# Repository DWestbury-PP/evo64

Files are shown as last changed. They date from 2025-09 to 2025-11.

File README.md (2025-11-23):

# EVO64 Project

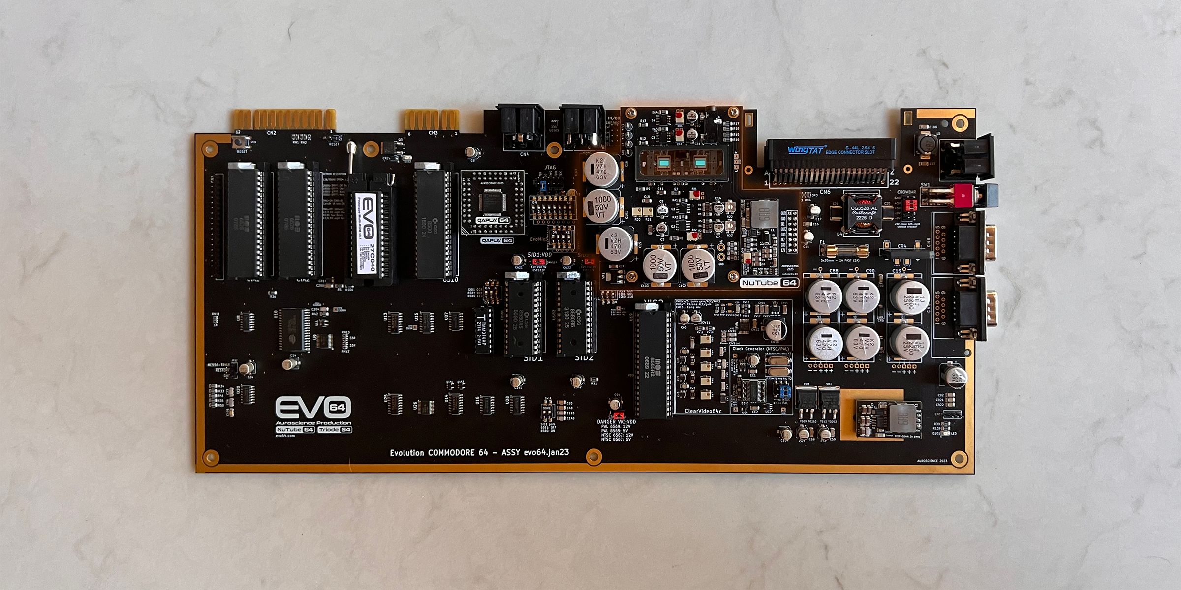
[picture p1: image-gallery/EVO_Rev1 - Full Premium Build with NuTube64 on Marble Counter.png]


## About EVO64

**EVO64** is a reimagining of the classic Commodore 64 with modern features and flourishes. This project brings the beloved C64 experience into the modern era while maintaining the authentic retro computing spirit that made the original so special.

### Key Features
EVO64 Logo

- **Modern Hardware Design** - Updated internals with contemporary components
- **Authentic Experience** - Maintains the classic C64 look, feel, and compatibility
- **Premium Build Quality** - High-quality components and construction
- **Extensive Documentation** - Comprehensive guides for builders and users
- **Community Support** - 3D printable accessories and mounting solutions

---

## Repository Contents

This repository contains supporting materials for the EVO64 project. While the hardware design and schematics remain proprietary, we're sharing essential resources for the community:

### Documentation (`/documentation/`)
Comprehensive guides and technical documentation:
- **EVO64 DIY Build Guide.pdf** - Complete assembly instructions
- **EVO64 Getting Started Guide.pdf** - Setup and initial configuration
- **EVO64 Product Brief.pdf** - Project overview and specifications
- **Technical Guides** - SID Audio, ROM Management, Tube Preamps, and more
- **Bill of Materials (BOM)** - Component lists for different configurations
- **MSM Command Sheet** - printable quick references by Retrosarge

### Image Gallery (`/image-gallery/`)
High-quality photos showcasing different EVO64 builds:
- Premium builds with NuTube64 and Triode64
- Various case configurations (Breadbin, Plexilaser, MODULR)
- Assembly photos and finished systems
- Prototype and development images

### Marketing Materials (`/promo-marketing/`)
- Project advertisements and promotional graphics

### 3D Printables (`/3D-printables/`)
Community-contributed 3D printing files organized by creator:
- **LCD Mounts** - 16x2 and 20x4 display mounting solutions
- **Keyboard Mounts** - Various case compatibility options
- **Cart Shield Covers** - Cartridge port protection
- **MSM Mounts** - Multi Switch Module mounting hardware
- **SIDKick & VIC-II Kawari** - Accessory housings
- **Case-Specific Mounts** - Plexi, C64c, and MODULR case accessories

### Interactive BOMs (`/ibom-html/`)
- Interactive HTML bill of materials for easy component identification

---

## Getting Started

### Prerequisites

This repository uses **Git Large File Storage (Git LFS)** to handle large files efficiently. You'll need:

1. **Git** (standard installation)
2. **Git LFS** - For handling large documentation PDFs, images, and 3D files

### Installation

#### Install Git LFS

**macOS (Homebrew):**
```bash
brew install git-lfs
```

**Windows:**
Download from [git-lfs.github.io](https://git-lfs.github.io/)

**Linux (Ubuntu/Debian):**
```bash
sudo apt install git-lfs
```

#### Clone the Repository

```bash
# Clone the repository
git clone https://github.com/[username]/evo64.git
cd evo64

# Initialize Git LFS (one-time setup)
git lfs install

# Pull all LFS files
git lfs pull
```

---

## Large Files Information

This repository contains **90 files** managed by Git LFS, totaling approximately **411 MB** of content including:

- **Documentation PDFs** (up to 123MB each)
- **High-resolution images** (up to 30MB each)
- **3D printing files** (STL and 3MF formats)
- **Excel spreadsheets** (BOMs and specifications)

### File Types Tracked by Git LFS:
- `*.pdf` - Documentation and guides
- `*.png`, `*.jpg`, `*.jpeg` - Images and photos
- `*.stl`, `*.3mf` - 3D printing files
- `*.xlsx` - Spreadsheets and BOMs

### For Contributors

When contributing new files:
- **Large files** (>25MB) will automatically be tracked by Git LFS
- **No special commands needed** - just add and commit normally
- The `.gitattributes` file handles LFS routing automatically

---

## Project Structure

```
evo64/
├── 3D-printables/             # Community 3D printing files
│   ├── Cart Shield Cover/     # Cartridge port covers
│   ├── Keyboard Mounts/       # Various keyboard mounting solutions
│   ├── LCD Mounts/            # Display mounting hardware
│   ├── MSM Mounts/            # Multi Switch Module mounts
│   └── [Various creators]/    # Organized by contributor
├── documentation/             # Technical documentation and guides
├── ibom-html/                 # Interactive bill of materials
├── image-gallery/             # Project photos and showcase images
├── Multi-SID Tester           # Player tool to test SID Addresses
├── promo-marketing/           # Marketing and promotional materials
└── README.md                  # This file
```

---

## Contributing

We welcome contributions to the supporting materials! Here's how you can help:

### 3D Printables
- Submit STL/3MF files for new mounting solutions
- Include photos of printed parts and installations
- Provide clear documentation for your designs

### Documentation Improvements
- Corrections and clarifications to existing guides
- Additional setup instructions for different configurations
- Translation contributions

### Images
- High-quality photos of your EVO64 build
- Different case configurations and setups
- Assembly process documentation

### Contribution Process
1. Fork the repository
2. Create a feature branch (`git checkout -b feature/new-mount-design`)
3. Add your files and documentation
4. Commit your changes (`git commit -m 'Add new LCD mount for XYZ case'`)
5. Push to the branch (`git push origin feature/new-mount-design`)
6. Open a Pull Request

---

## Important Notes

- **Hardware Design**: The PCB schematics and hardware design files are not included in this repository
- **Commercial Use**: Please respect any licensing terms associated with contributed files
- **File Sizes**: Large files are automatically handled by Git LFS - no special action required
- **Dependencies**: Some 3D printable designs may require specific hardware or case types

---

## Support & Community

- **Issues**: Report problems or request features via GitHub Issues
- **Discussions**: Join community discussions in GitHub Discussions
- **Documentation**: Check the `/documentation/` folder for detailed guides

---

## License

See the [LICENSE](LICENSE) file for details regarding the use of materials in this repository.

Individual contributors may have specific licensing terms for their submissions - please check individual file headers and accompanying documentation.

---

## Acknowledgments

Special thanks to all community contributors who have shared their 3D designs, documentation improvements, and build photos:

- **Sedor** - Multiple 3D printable designs and mounts
- **Jaystonian** - Keyboard mounting solutions
- **Perifractic** - C64c case compatibility mounts
- **BattleQuest** - MSM mounting hardware
- **Retrosarge** - MSM command sheet quick references
- And many others in the EVO64 community!

---
- All technical engineering work, including initial project conception, PCB design and extensive build testing by Dr. Stefano (aka Auroscience)
- Inspiration came from Hans Petter Dalsklev who worked on the C64 assembly 250407 board layout
- Inspiration for the ClearVideo64 video circuit came from Jay Desmarais (Jaystonian), however EVO’s implementations are unique and distinct
- Inspiration for Multi-SID and multi-ROM circuits came from Henning Liebenau, however EVO’s implementations are unique and distinct
- Inspiration for the “HeyBirt” Voltage Controlled Oscillator (VCO) / MOS 8701 Clock replacement circuit came from Jeff Birt (HeyBirt)
- The EVO64 logo, case badges and other branding have been developed by the Retro Badgeman
- Social media, tech documentation, web site maintenance & “innovative ideation” by Darrell Westbury
- Beta builds, testing and engineering support by Darrell Westbury, M. Bernardo (aka SX64Man) and H. Eckert.

---

*EVO64 - Bringing the C64 experience to the modern era*

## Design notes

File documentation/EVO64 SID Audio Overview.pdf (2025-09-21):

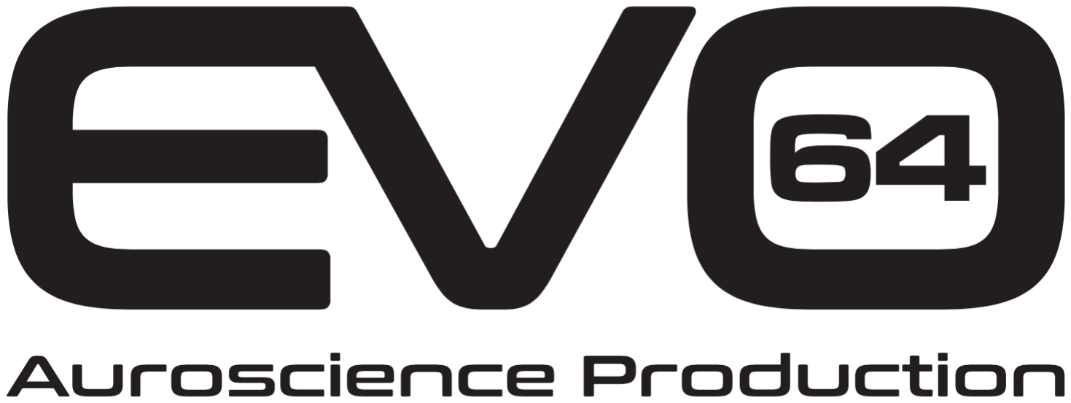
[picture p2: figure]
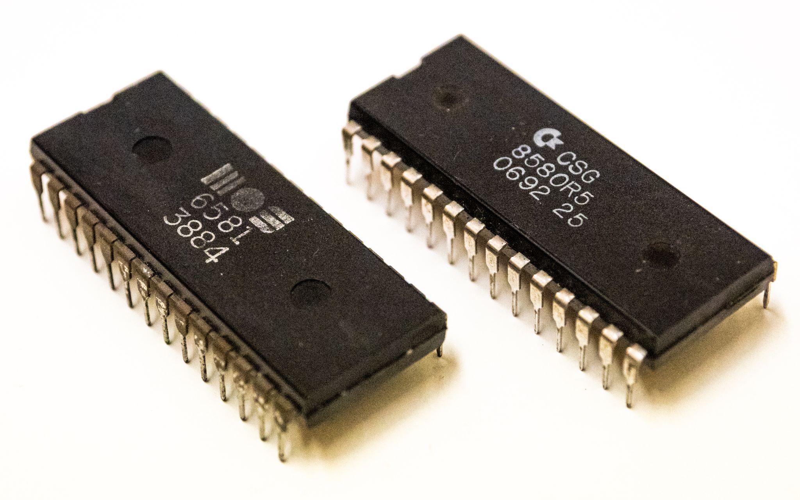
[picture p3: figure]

# “Double your Listening Pleasure”

One of the coolest features of the EVO is its native support for Dual SID chips and stereo sound output. The original inspirations came from the MixSID by Henning Liebenau, (http://henning-liebenau.de/mixsid/) although EVO takes a completely unique and novel approach by implementing all of its dual-SID addressing logic directly into a customized PLA we’re calling the QAPLA’. (https://docs.google.com/document/d/1FS7WOKs4T5evn5urdY_PP3zLMoXYe2qxybZdXSJ7aDo/edit?usp=sharing)

You may be familiar with some of the popular dual-SID solutions out there, which typically send the same (mono) audio signal to both SIDs at the same time. This can produce a nice “pseudo-Stereo effect”, when different types of SID chips are used (e.g., one 6581 and one 8580). This is due to the fact that your ears are hearing the different sound characteristics from the different chip models. EVO can reproduce this effect too of course, but it also goes much further…

EVO provides “True Stereo Sound”, by exposing the second SID to its own unique memory addresses. This enables different notes and effects to be played from each SID, providing software with access to 6x oscillator voices and 2x filters, for double the fun.

To ensure the best backwards compatibility, the primary SID on your EVO will always listen on address $D400, and by moving a simple jumper, you can select which of your two SIDs will act as the primary at any given time. By default, your second SID will receive notes and instructions from both $D420 and $D500, which enables great support for most of the popular dual-SID tracks in the HVSC, (https://www.hvsc.c64.org/) as well as many of the great dual-SID capable games, like the new Mario Brothers. You can also make your own stereo SID music, with composer software like the CYNTHCART. (https://www.protovision.games/shop/product_info.php?products_id=195) Moving another jumper will allow the second SID to listen on $DE00 and $DF00 as well, which provides even further compatibility for tools like the MSSIAH (https://www.mssiah.com/) music composition cartridge, and other music players.

Best of all, EVO lets you use any SID chip variant(s) that you prefer, from the earliest generation 6581, with its gnarly oscillators and filter glitches (operating at 12v), to the clean and pristine 8580 (operating at 9v). And as you would expect, EVO is also fully compatible with the most popular SID clones, like the ARMSID, (https://retrocomp.cz/produkt?id=2) the FPGA SID, (https://www.fpgasid.de/) the SwinSID (http://www.tolaemon.com/nss/) and the SwinSID Ultimate, (https://www.polyplay.xyz/SwinSID-Ultimate_1) the BackSID, (https://store.backbit.io/product/backsid/) etc. Best of all, you can mix and match any combination of SIDs that you like, to get the best version of that retro sound you’ve been hearing in your head.

Some suggestions for enjoying SID Music:
- Download the latest High Voltage SID Collection (HVSC), (https://www.hvsc.c64.org/) which contains over ~57,500 SID tunes, spanning the entire history of the C64, including all your favorite games and demos
- Check this handy reference if you just want to hear the dual-SID tracks, (https://docs.google.com/spreadsheets/d/1RV7PpcfUeuKZvfKBUschUJkIjfavsCjFWxMSMw_W-gg/edit#gid=0) organized by the year they were added into the HVSC
- You can enjoy your favorite SID tracks pretty easily if you happen to have an Ultimate II+ Cartridge, (https://ultimate64.com/Main_products) or the SIDEKick, (https://github.com/frntc/Sidekick64) which have their own built-in SID player apps
- You can also download SIDPlay64, (https://drive.google.com/file/d/115wgpOQB7c2ugfRSOcJBukWw_piem4bS/view?usp=sharing) which comes in a variety of different versions for accessing different types of storage devices. There’s a version that works well with standard disks, one for the SD2IEC device, one for use with a Ram Expansion Unit (REU), etc., etc.

The following pages provide the necessary configuration steps to help you get your EVO64 system setup to support the SIDs (or clones) of your choice, with multiple options for audio output signal routing.

Please enjoy!

## Jumper Settings for Dual-SID Control

The quick reference table below provides information to help with jumper configurations and DIP switch settings that are needed to ensure that your SID chips are working properly and providing their best quality audio output, as well as full support for analog devices like paddles and a mouse

A | & | C | SID Voltage Selection*

B Multi-SID Mode Selection

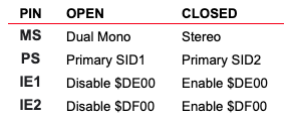
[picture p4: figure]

D | & | F | SID Filter Capacitor Type

E SID Paddle Capacitor Type

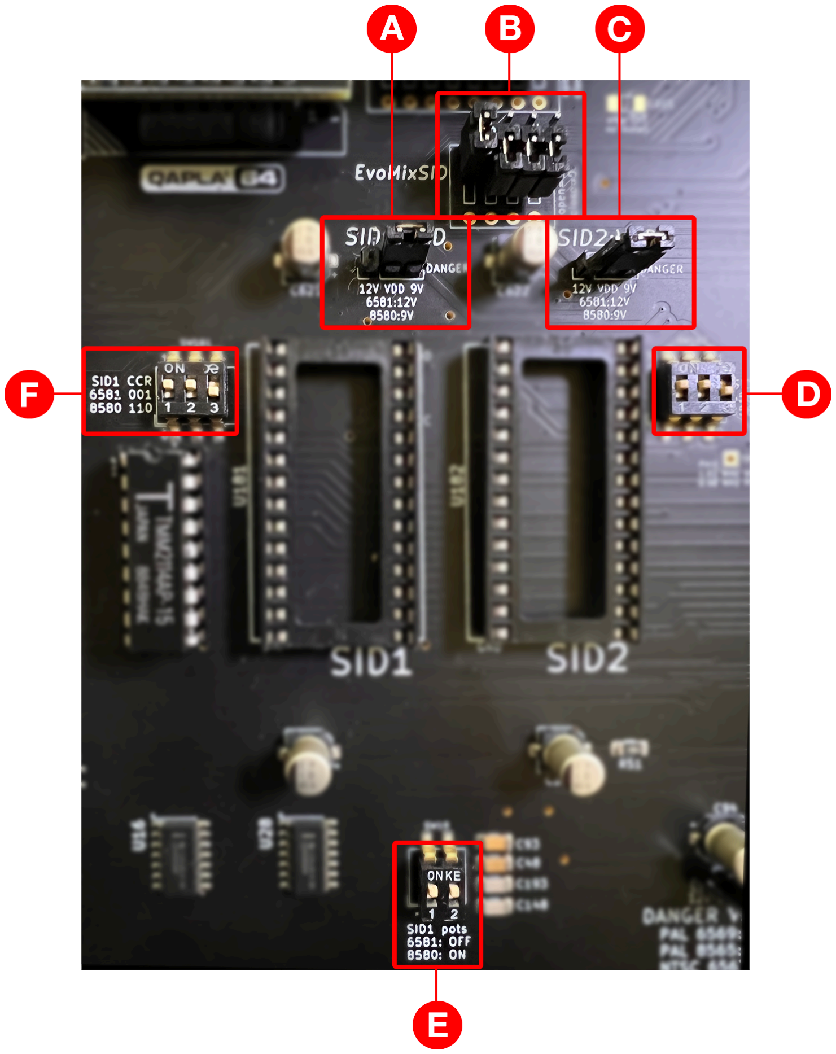
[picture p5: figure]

*IMPORTANT*
- Never make changes to voltages while your system is powered on!
- Sending 12v into a 8580 could fry it (quickly). Be sure to double and even triple check your voltage settings before powering up your system
- Your SID chips are likely to sound terrible if you select the wrong filter capacitor setting ( D & -F- above), so ensure that you have the correct type selected whenever you chance SID chips

## EvoMixSID Array Bank

The next section provides a bit more insight into the various multi-SID operations that EVO supports.

NOTE: All runtime control signals are pulled up to “logic HIGH” internally when no jumper is connected. In other words, the top row contains the actual signals, while all pins on the bottom row are all connected to ground (GND)

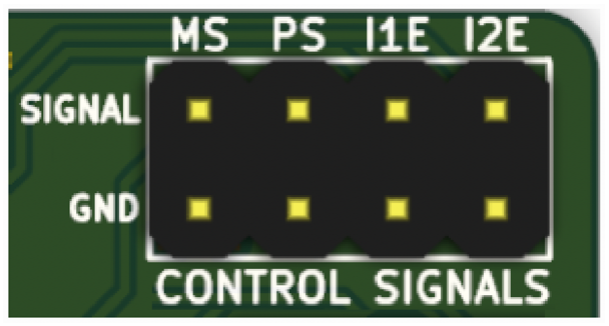
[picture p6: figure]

These pins can either be left unconnected (HIGH) or connected to GND (LOW). These signals can be freely changed at runtime, without worrying about crashing the system, so feel free to experiment with different settings while the machine is turned on and playing music!

## Mode Select (MS)

The mode select line switches between parallel or stereo addressing modes:

Parallel Addressing Mode (Jumper OPEN = HIGH)
This mode should be used when playing back normal SID tunes which expect just one SID at $D400. Both SIDs are addressed in parallel, so both are available on $D400 in this mode, and they’ll both playback the same tune.

In this mode, the secondary SID is forced into write-only, while the primary SID remains both read and write. So, only the primary SID will respond to read requests to the readable SID registers (POTX, POTY, OSC3 and ENV3). This way paddles and mice as well as sound effects that are based on reading OSC3 or ENV3 will work as usual.

If you install SIDs that differ in sound (either a 8580 and a 6581, or two different 6581 versions with audible differences) and listen to each SID on a different stereo channel, you will notice the aforementioned Pseudo-Stereo effect, even while playing a simple mono tune. This results from the SID differences. Whether or not this sounds good to you is highly subjective, and will mostly depend on the tune itself.

Stereo addressing Mode (Jumper CLOSED = LOW)
This mode can be used when playing back tunes that were explicitly created for two SID chips.

When in stereo addressing mode, the primary SID will be addressed at $D400 while the secondary SID will be addressed at both $D420 and $D500 simultaneously. Most stereo tunes that were tested seem to expect the second SID at one-of-these-two addresses (e.g., a majority of the *2SIDs in the High Voltage SID Collection).

If the IO Enable signals are used, the secondary SID will additionally be addressed at $DE00 and/or $DF00. While fewer tunes expect the second SID at these addresses, some hardware extensions may want to see the second SID there (e.g., the MSSIAH Cartridge), however these addresses may conflict with some software and cartridges (e.g., the RetroReplay), so it’s best not to enable these addresses unless you know that you need them.

## Priority Select (PS)

The priority select signal controls which SID takes the role of primary and which takes the role of the secondary.

The primary SID will always be read-write at $D400. However, the secondary SID will either be write-only at $D400 when Mode Select is set to parallel addressing mode, or it will be full read-write when Mode Select is set to stereo addressing mode (see Mode Select for more details).

If this signal is HIGH (e.g, jumper OPEN), the SID in the right socket (labeled SID1) will be the primary SID. If the signal is LOW (e.g., jumper CLOSED), the SID in the left socket (labeled SID2) will be the primary SID.

Effects on software SID detection
A common method for detecting the model of the installed SID from within a C64 program involves reading the OSC3 and ENV3 registers.

Since only the primary SID will respond to read requests, the priority selection also controls which SID model is detected by software in a mixed setup.

Effects on paddle accuracy
The POTX and POTY lines will always be routed to the primary SID, which will then measure and report the current paddle position to the software reading the POTX and POTY registers.

The actual values measured by the SID depend on the value of the capacitors externally connected to the POTX and POTY lines .

Since different values were used on different mainboards (depending on the SID model usually used on that main board), the measurements will be slightly off if a SID model is used as the primary SID that is not native to the board.

For example, when using a 8580 as the primary SID on a 250407 mainboard, the values read from the paddle can be off by about ~5%.

However, this hardly matters in practice since the complete range of values can still be reached by turning the paddle knob. This is only a problem if the middle position of the paddle absolutely has to yield a value of 127. In this case, use at least one SID model that is native to your mainboard type, and set it to be the primary SID when using paddles.

## IO Enable (I1E, I2E)

The I1E and I2E signals control whether or not the secondary SID also appears at the corresponding stereo addresses $DE00 or $DF00 when in stereo addressing mode (e.g., Mode Select [MS] must be set to Stereo Address Mode [Jumper Closed]).

HIGH (Jumper Open): 2nd SID does not appear at corresponding IO-Area address
LOW (Jumper Closed): 2nd SID does appear at corresponding IO-Area address

This feature allows the user to permanently connect the I/O signal lines to the board, but still control at runtime whether or not they are used for stereo mode.

## SID Audio Amplifier Control

You have complete control over which Audio output signal(s) will flow through through your system’s 8-Pin Audio / Video jack on the rear of your system. You can choose to leverage the built-in “transistor-based amplifiers” or if you happen to have one of the optional audio preamp modules (the NuTube64 or Triode64), (https://docs.google.com/document/d/1PIr6p0sui0dLlgHLj0wzGMUa09k3J9Dm_O-cMAILEqE/edit?usp=sharing) you can direct their fully processed and colorized audio output through your A/V port.

Even if you have a preamp module, we think that most people will still choose to use the built-in transistor amps for their standard audio output that will flow into their monitor and/or speakers, since this will produce the type of line level audio output signal that those devices are expecting.

Using one of the 3.5mm (1/8th inch) jacks on the back of the preamp module is going to be the best way to capture the processed and warmed audio output, which you will most likely want to send into an amplifier, a sound card for a DAW or higher quality set of powered monitor speakers.

This same section of the EVO board also includes a set of potentiometers that allow you to make small adjustments to the gain levels for each of your SIDs independently. These ensure that you’ll always have properly matched audio output levels from your left and right channels (stereo or dual-mono), even when you’re mixing and matching with different types of SIDs models, which vary in their output levels.

The table below provides a quick reference to help configure the SID audio routing and output levels.

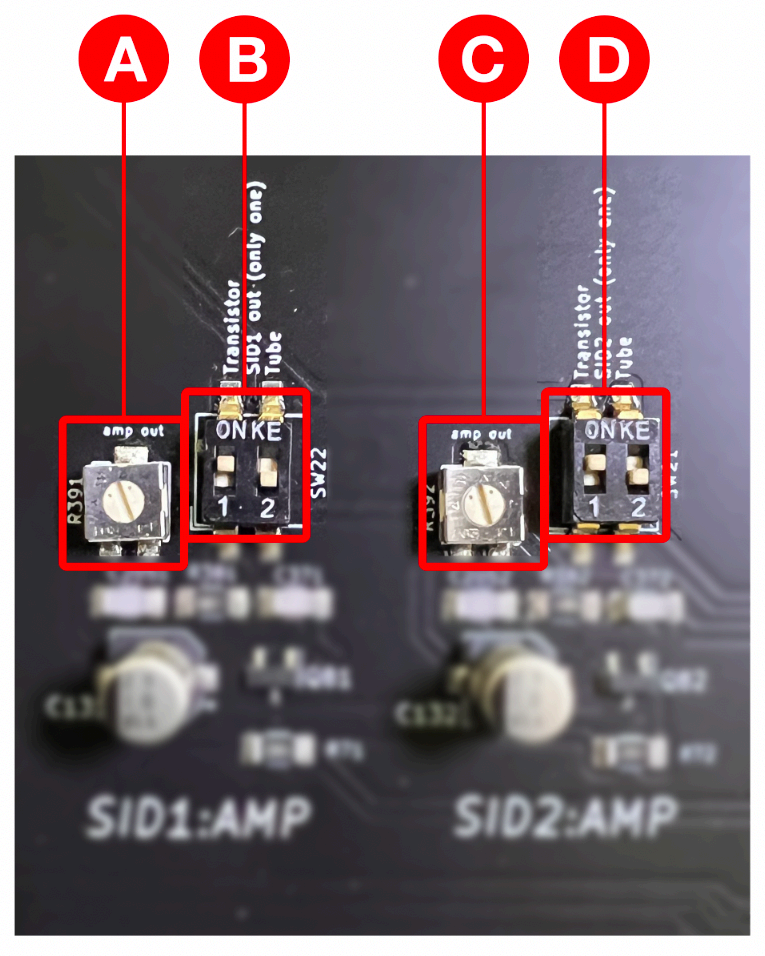
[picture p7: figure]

A | & | C | SID Amplifier Gain Level

Use a small screwdriver to make fine adjustments to these potentiometers, which allow you to rebalance the gain levels for each of your SID chips independently. Audio is sent to the 8-Pin Audio / Video port on the rear of the system

TIP: It’s best to make these adjustments while you are playing back SID music and listening closely to the audio output

B | & | D | SID Audio Amplifier Selection

These DIP switches control which audio output (e.g., internal amp vs. optional preamp add-on) will be sent to the 8-Pin DIN Audio / Video port on the rear of the system*

*Be sure to select only one audio routing option.

## Selecting the A/V Audio Output Pin for your Second SID

The original C64 systems didn’t have multiple SIDs, so by default the built-in 8-Pin DIN Audio / Video (AV) jack on the back of a standard C64 system wouldn’t have support for the second SID’s audio output.

Fortunately EVO has you covered there, allowing you to select which of the unused AV jack pins you would prefer to use to capture audio from the second SID.

The most common standard nowadays is to use Pin-7, but some people have a preference for Pin-5, depending on the types of AV cables they may already have lying around.

NOTE: If you received a pre-assembled EVO, it will likely have already been configured to use Pin-7, so you can skip this section and avoid any soldering

The table below provides a quick reference to help configure a series of solder-pads on the UNDERSIDE of the EVO, which are located right below the Audio / Video port (AV). These pads control the audio input and output signal routing, in to and out from the AV port.

*IMPORTANT* This configuration step is required in order to be able to hear audio output from SID #2, irrespective of whether you plan to use Dual-Mono or Stereo mode

B SID #2 Audio “Output” to AV Pin 5*

OPTION #1: Shorting the middle and bottom pads will send SID #2 audio output to AV pin 5. You must have a custom AV cable that supports this (see the next section below)

OPTION #2: Shorting the top and middle pads will configure AV Pin 5 to accept an external audio signal “IN” to your system on AV Pin 5. This feature not recommended as it could introduce noise into the system

*Do NOT short all three of these pads, or try to combine options 1 & 2. This will cause audio distortion!

C SID #2 Audio “Output” to AV Pin 7

Shorting these pads will send SID #2 audio output to AV pin 7, which is the most common choice for most of the stereo AV cables that have been made available for the Commodore 64 over the years

You need an A/V breakout module or a custom cable that supports dual-SID output (see next section)

TIP: Pin 7 is the most widely recommended option for capturing stereo audio output from the C64

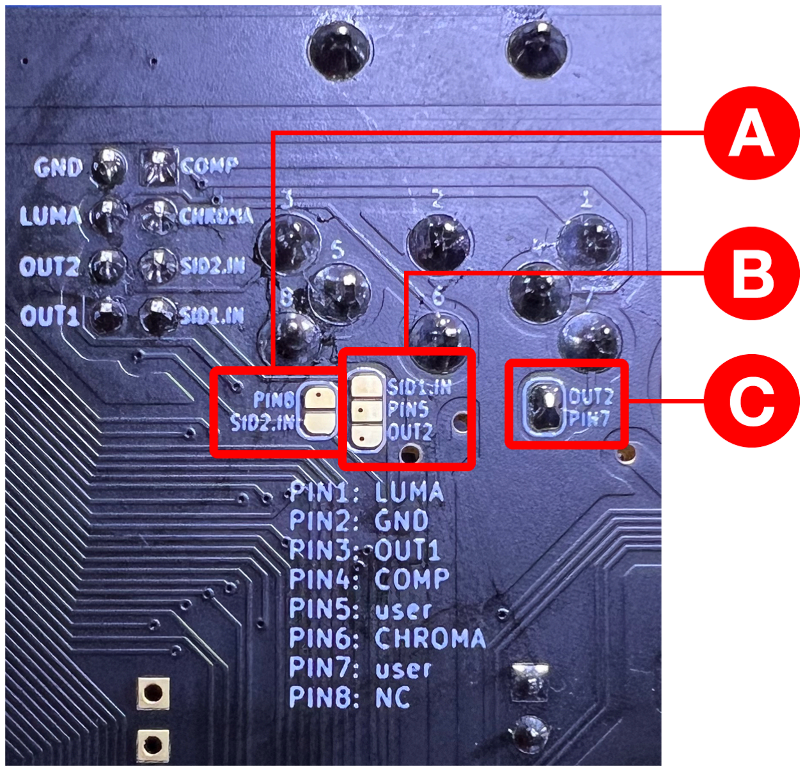
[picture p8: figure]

A Audio “Input” to SID #2 (optional)

Shorting across these pads will enable you to send an external audio signal “IN” to your system over AV pin 8, which will be directed to the SID #2. This feature is not recommended as it could introduce noise into the system

## Audio / Video Cables (AV)

Most of the standard AV cables made for the C64 are not going to provide support for a second SID’s audio output. This leaves you with a few choices to consider.

OPTION 1: You can buy a modern AV cable from a supplier like 8 Bit Classics, (https://www.8bitclassics.com/product/c64-svideo/) which supports second-SID audio through Pin-7 of the AV jack (note: we are not affiliated with or compensated by them)

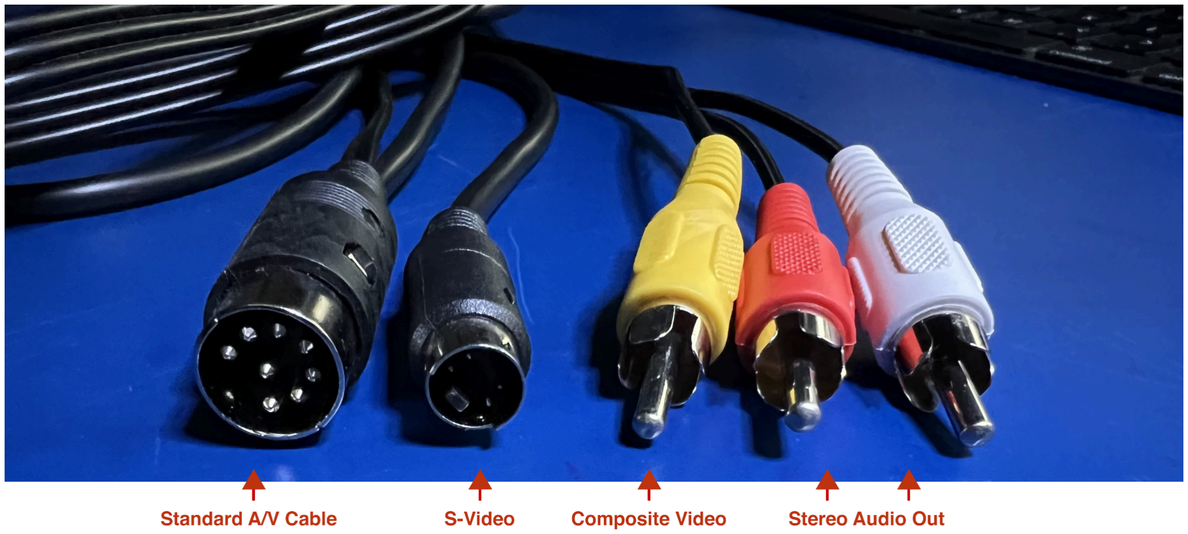
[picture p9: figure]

OPTION 2: You can pick up a nice breakout module from the Retrospective shop, (https://retrospective.shop/audio-video-breakout-module/) which can plug directly into your system’s AV Port and provide separate output signals for the left and right audio channels, as well as separate signals for composite and S-Video. This approach enables you to use standard off the shelf RCA and S-Video cables, which are widely available from many retailers.

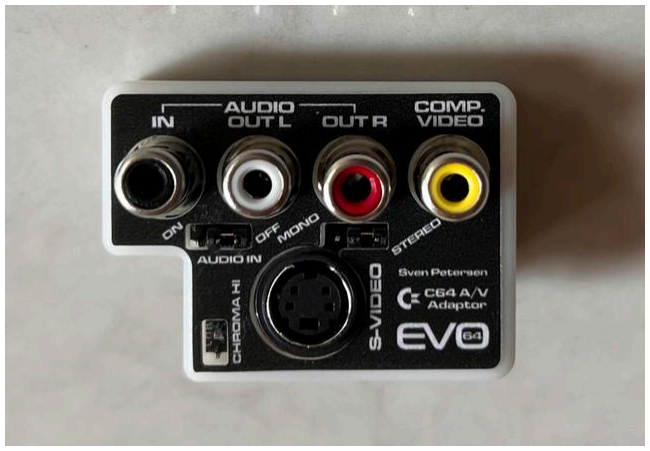
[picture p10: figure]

OPTION 3: You can have your own AV cable(s) made, by following the specification below, but you’ll need to be mindful of the details. The C64’s 8-Pin DIN uses a “horseshoe shaped” configuration at a 262 degree angle. There are other 8-Pin connector standards with pins on different angles, which won’t fit your machine properly!

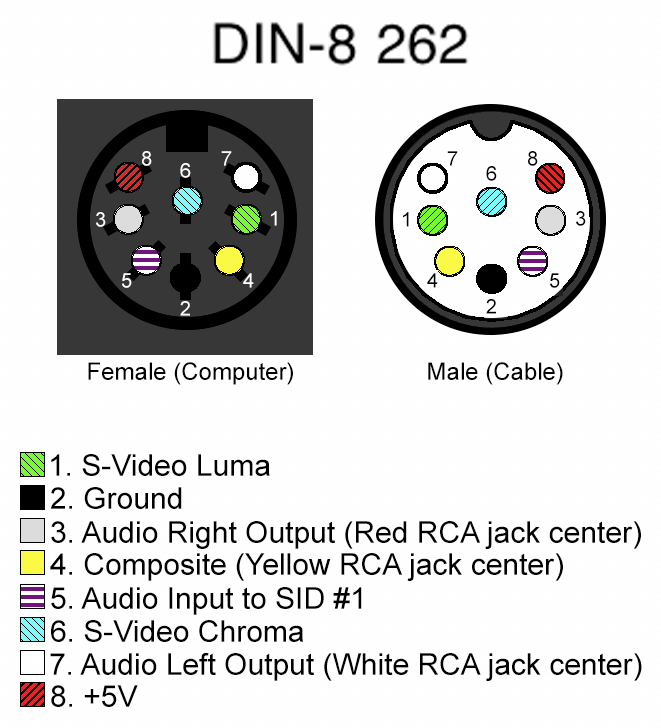
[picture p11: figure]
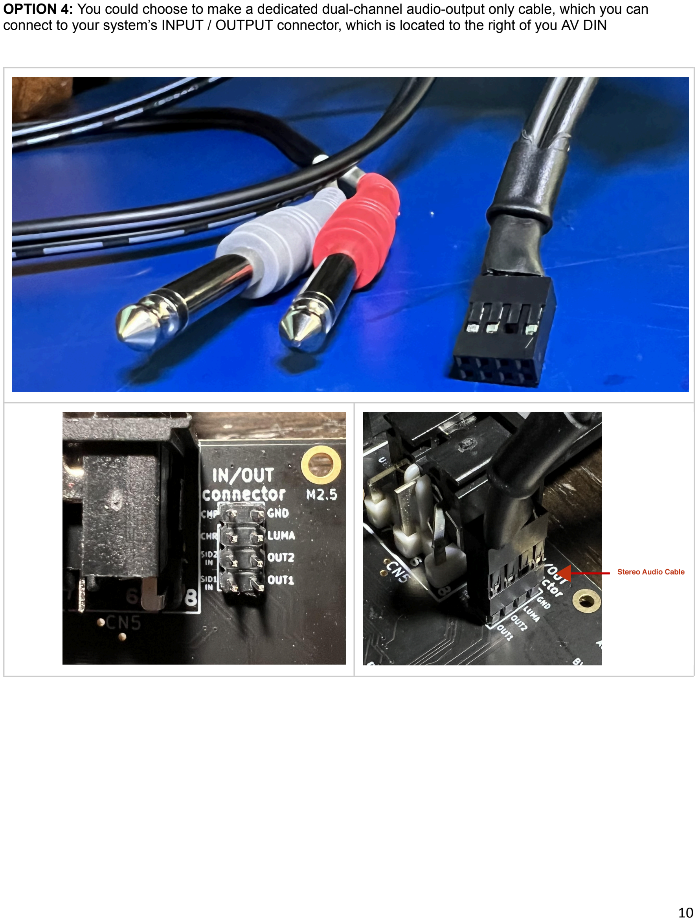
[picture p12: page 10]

OPTION 4: You could choose to make a dedicated dual-channel audio-output only cable, which you can connect to your system’s INPUT / OUTPUT connector, which is located to the right of you AV DIN

## For Audio Preamp Users

If you’re planning to use any of the audio preamp modules being made available for EVO (e.g., the NuTube64 or the Triode64), please refer to the appropriate documentation (https://docs.google.com/document/d/1PIr6p0sui0dLlgHLj0wzGMUa09k3J9Dm_O-cMAILEqE/edit?usp=sharing) for installation and setup, which will ensure that you’re always having the best audio experience with them.

NuTube64 (Gen 3) | Triode64 (Gen 1)

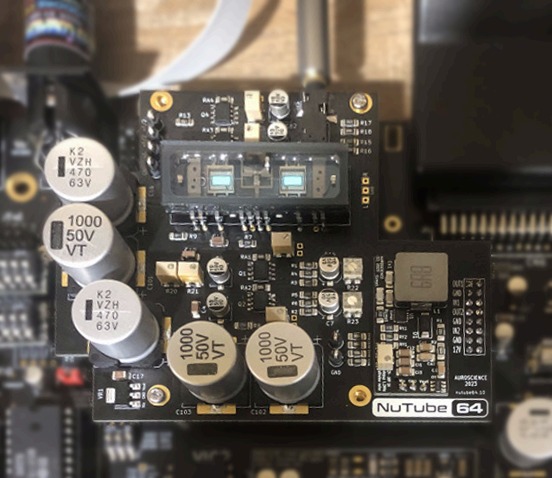
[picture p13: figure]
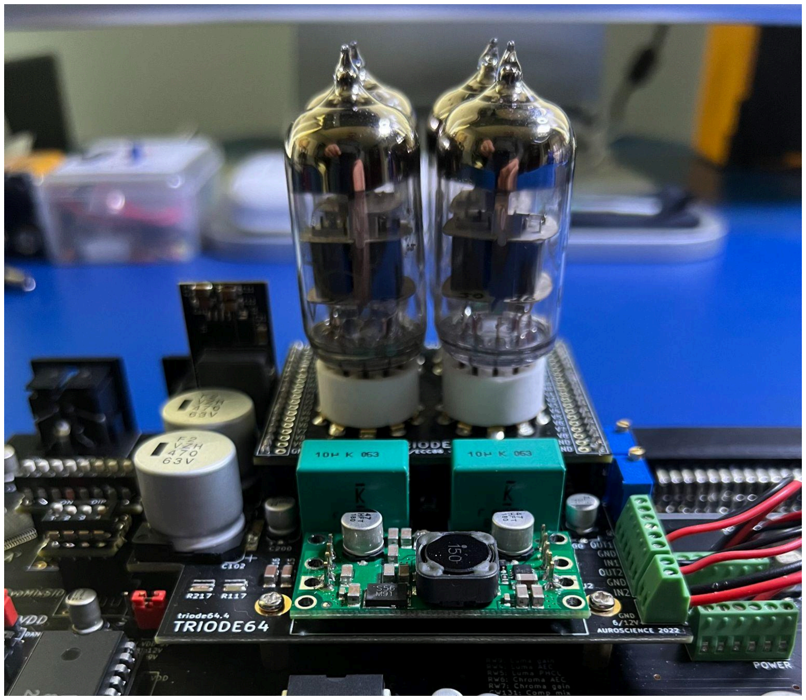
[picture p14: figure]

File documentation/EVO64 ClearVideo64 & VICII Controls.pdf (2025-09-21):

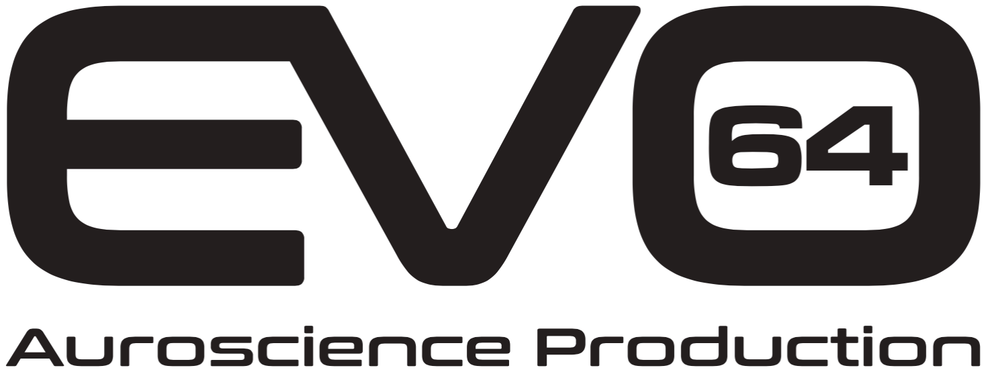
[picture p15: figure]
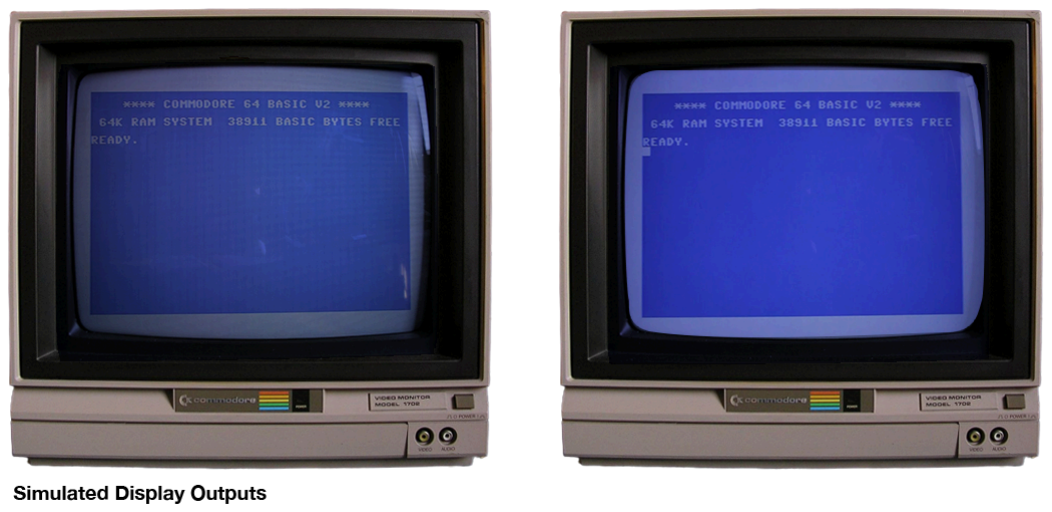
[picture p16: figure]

## “Escape from Behind those Bars”

Retro hardware fans like us are typically faced with a dichotomy. We LOVE the look and feel of our old displays, because when we have them tuned just right, our games and demos become more like a time-machine, teleporting us back to the most nostalgic places in our imaginations.

However, we also know that old hardware can be a royal pain in the “you know what” to manage and maintain, as it degrades over time. One of those challenges comes in the form of video distortion that can proliferate from dirty power sources, leaking signals in the PCB, external EMF, etc., etc.

Over the years, various techniques have been developed that have helped to reduce some of these effects, such as eliminating the old RF Bypass circuit, installing a lumafix, implementing video amplifiers, etc.

One of the most notable solutions came from Jay Desmarais (aka Jaystonian) (https://github.com/Jaystonian/ClearVideo) with his ClearVideo circuit. He took the idea of using a high quality video amp (the THS7316), with an enhanced Lumafix, then went much further, by providing the ability to selectively inject inverted versions of the most common noise sources back into the video signal (e.g., the RAS, CAS, PHI, etc.).

## EVO’s ClearVideo64 Circuit and VICII Controls

EVO incorporates a modified version of the ClearVideo circuit, which includes some extra features and niceties, such as additional tuning adjustments, which help to reduce noise even further.

EVO provides a series of jumper headers that allow you to select the required voltage levels for the VIC-II chip(s) that you intend to use*:

Voltage | PAL VIC-II Chips
12v | MOS 6569 – (PAL-B, used in most PAL countries)
12v | MOS 6572 – (PAL-N, used in southern South America only)
12v | MOS 6573 – (PAL-M, used in Brazil only)
5v | MOS 8565 – HMOS-II version for "C64E" motherboards
Voltage | NTSC VIC-II Chips
12v | MOS 6567 – Original NMOS version
5v | MOS 8562 – HMOS-II version

EVO also includes an onboard clock generator circuit, which provides a rock solid and jitter free voltage controlled oscillator (VCO) signal. This design was inspired by the original work done by Jeff Birt (aka Hey Birt), (https://github.com/Jeff-Birt/MOS8701_HB) although EVO takes this things a bit further, by enabling you to selectively activate either a PAL or NTSC timing crystal, so you can enjoy a wider selection of software titles.

The table below highlights the areas on the EVO board where VIC-II voltages and PAL/NTSC timings can be setup*

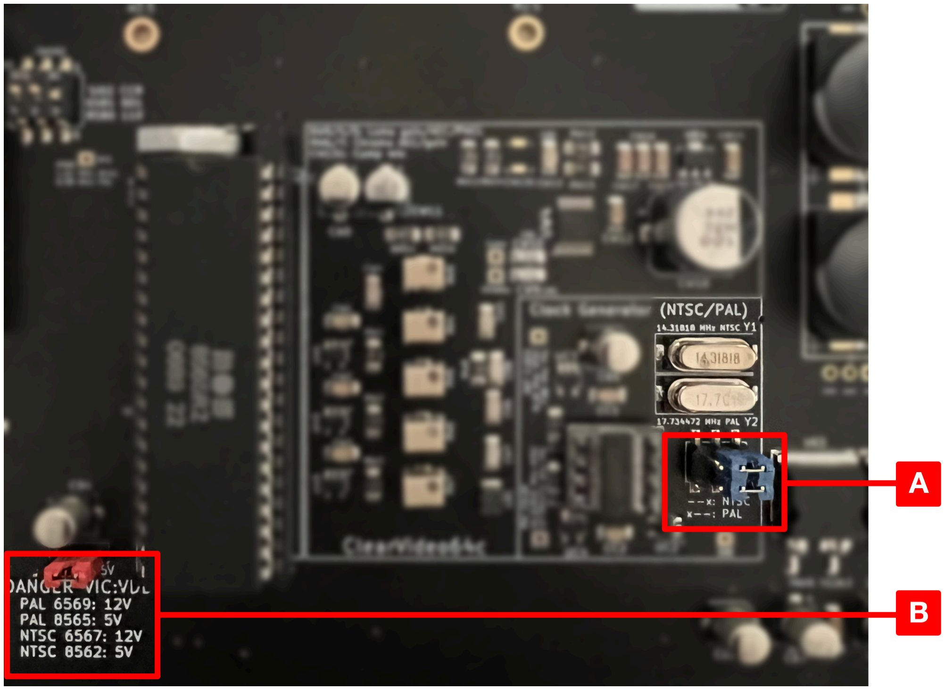
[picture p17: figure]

A PAL / NTSC Switching*
Separate jumpers are here for the Dot clock & the PHI color clock. *Be sure to move both jumpers

B VIC-II Voltage Config*

*CAUTION* Supplying 12V to a 5V VIC-II is likely to fry it

*IMPORTANT NOTES:
- Always reference the table above when changing your VIC-II chip, to ensure that you’re providing the correct voltage.
- Passing too much voltage can completely destroy your VICII chip
- Passing too low of a voltage won’t allow it to work
- Always ensure that your system is powered off before attempting to change any voltages

NOTE for Kawari VIC-II Replacement Users:
The Kawari (https://github.com/randyrossi/vicii-kawari) by Randy Rossi is a wonderful replacement option for the aging VIC-II chips, which are becoming more difficult to find and more expensive to source, with the likelihood that they will eventually fail increasing over time.

You’ll be happy to know that we have successfully tested both the Kawari-Large and the Kawari-Mini with EVO, in both PAL and NTSC modes, while using either 40 and 80 column output. In our testing experience, the video output looks absolutely terrific, with accurate and stable screen raster timings.

1. Be sure to let Randy know that you intend to use your Kawari with EVO, since he will want to provide you with an SRAM compatible “core” (firmware code) that will ensure the best results (as of this writing, the v1.14 core is tested to work well with EVO in both PAL & NTSC video modes)
2. Referencing the VIC-II Voltage Config settings in the above diagram, you should configure your EVO board to provide 5V to your Kawari

## Tuning your Video Output for Perfection

The type and level of video distortion that your machine and monitor are producing will depend on a number of key factors, including input power sources, internal voltage regulator, the age and types of VIC-II chip(s) you are using, the stability, speed and jitter of your color clock and VCO, leakage from signals that are located near each other on the circuit board, as well as the types of displays you’re using (e.g., a CRT versus an LCD through a video upscaler, etc.).

Getting your video image “dialed in just right” is an iterative process. It will take a bit of time and patience to get it fully worked out, for the best possible image quality, but you’ll thank yourself when it’s done.

The table below highlights the areas on the EVO board where ClearVideo64c is located, highlighting the adjustable potentiometers that allow for gain level attenuation and noise reduction.

A RW9 - Luma Gain
Luminosity signal level adjustments

B RW4 - Luma AEC
Reduce noise from Address Enable Control

C RW5 - Luma PHCL
Reduce noise from Color Clock

D RW6 - Choma AEC
Reduce noise from Address Enable Control

E RW7- Chroma Gain
Chroma signal level adjustment

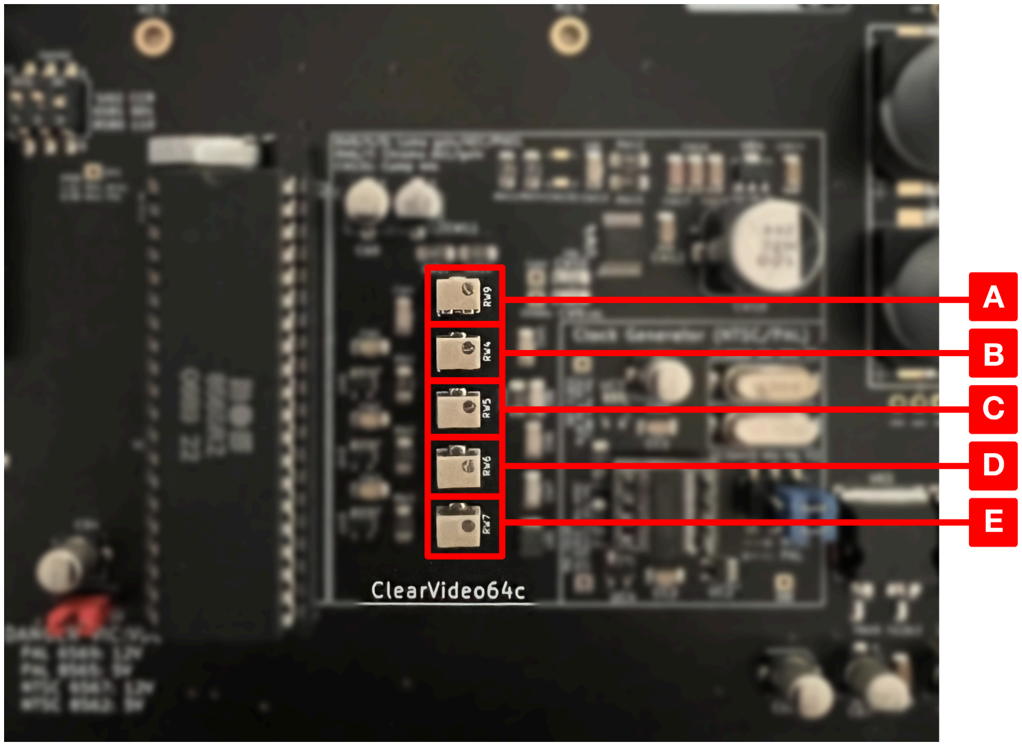
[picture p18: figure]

Eliminate those “Jail Bars” and “Tune Away” Video Noise

- Use a small 1.4mm flathead screwdriver to adjust all of the potentiometers clockwise, until they emit a faint clicking sound. You will need to rotate in a full 360 degrees, multiple times. They include a built-in protection that prevents over-rotation or damage
- Start by adjusting the middle potentiometer ( | C | RW5 - Luma PHCL), turning it counter-clockwise, until
you can see a ~50% overlap in video
- Now move up to the next pot ( | B | RW4 - Luma AEC) and adjust it slowly, until the picture starts to
improve a bit more. Jail bars should be starting to fade a bit now
- Move up to | A | RW9 - Luma Gain and adjust to taste in the same way, until the color level looks right
- Move down to | D | RW6 - Choma AEC
- Then finally to | E | RW7- Chroma Gain
- Now, go back and repeat the process, with smaller increments, beginning with RW5, then RW4, then RW9, etc., adjusting slowly, in +/- 2 turns, then move down to RW6 & RW7
Continue this iterative process until you’ve achieved your desired video output quality. There’s no right or

wrong settings here, it’s completely up to you…

Examples of common C64 display issues, due to various types of signal noise:

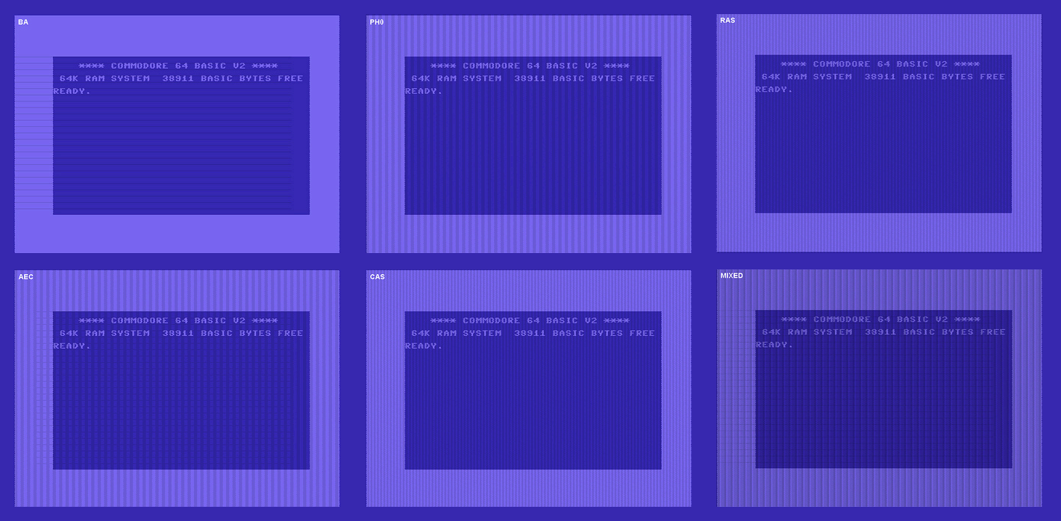
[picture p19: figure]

With EVO’s ClearVideo circuit, a couple of potentiometer twists can tune away any remnant noise or distortion, while boosting your color saturation and enhancing your text clarity. Best of all, you’ll finally be able to break free from those ugly jail bars!

Here’s some of the feedback we’ve been hearing:

“The best way I can describe this is that it looks fake. It’s like somebody connected an emulator up to my monitor instead of a real C64.” - David Murrary (The 8 Bit guy), Feb 1st 2023

“After my very brief setup process, we got rid of most of the jail bars… there's barely any… and usually they are pretty visible especially if you use modern screens…” - Jan Beta, Feb 4th 2023

“The audio and video is just engineered to an exacting standard here, it's amazing”
- Matt Demicco (Retrobits), Dec 29th 2022

## Audio / Video Cables (AV)

Most of the standard AV cables made for the C64 are not going to provide support for a second SID’s audio output. This leaves you with a few choices to consider.

OPTION 1: You can buy a more modern AV cable from a supplier like 8 Bit Classics, (https://www.8bitclassics.com/product/c64-svideo/) which supports second-SID audio through Pin-7 of the AV jack (note: we are not affiliated with or compensated by them)


OPTION 2: You can pick up a nice breakout module from the Retrospective shop, (https://retrospective.shop/audio-video-breakout-module/) which can plug directly into your system’s AV Port and provide separate output signals for the left and right audio channels, as well as separate signals for composite and S-Video. This approach enables you to use standard, off the shelf RCA and S-Video cables, which are widely available.


OPTION 3: You can have your own AV cable(s) made, by following the specification below, but you’ll need to be mindful of the details. The C64’s 8-Pin DIN uses a “horseshoe shaped” configuration at a 262 degree angle. There are other 8-Pin connector standards with pins on different angles, which won’t fit your machine properly!


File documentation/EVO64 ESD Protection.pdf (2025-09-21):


# Fried Chips are Overrated

Nothing will dampen your retro fun quicker than an electrostatic jolt from your hand or from an I/O port connector. Chips that tend to be the most vulnerable to ESD impact are the SID which controls your sound and the CIAs which control all of your input and output operations (e.g., keyboard, disk drive, dataset, timers, etc.).

Luckily, EVO has you covered, with a set of fully integrated ESD protection chips, which are strategically placed near the primary I/O cable inputs. Any static charges will be immediately grounded, which protects your precious system and preserves those increasingly difficult to replace MOS chips… Oh, you’re welcome!

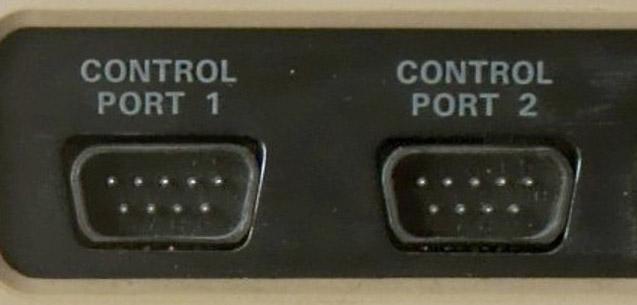
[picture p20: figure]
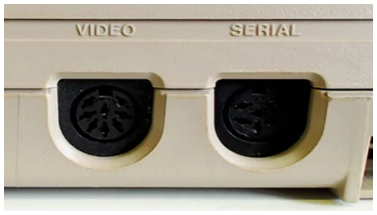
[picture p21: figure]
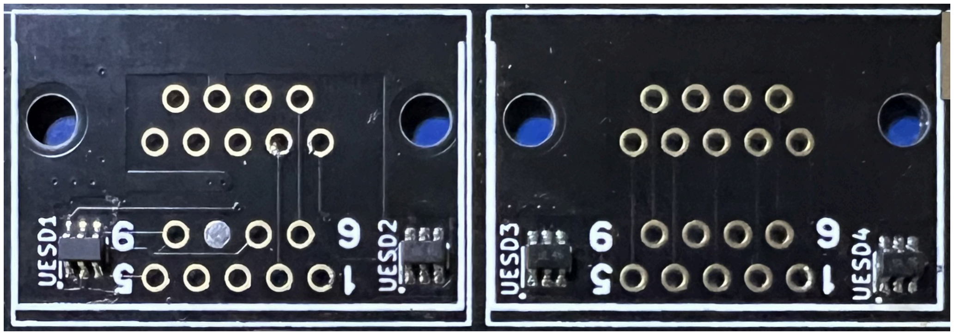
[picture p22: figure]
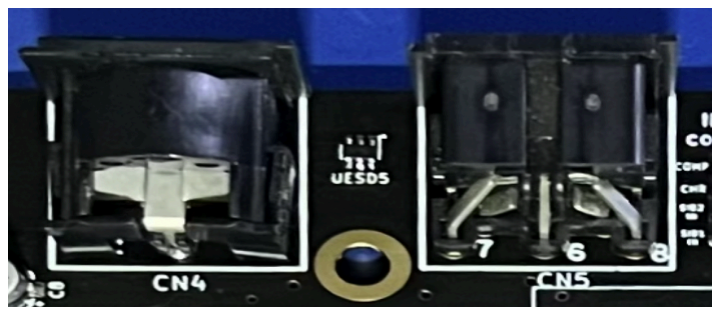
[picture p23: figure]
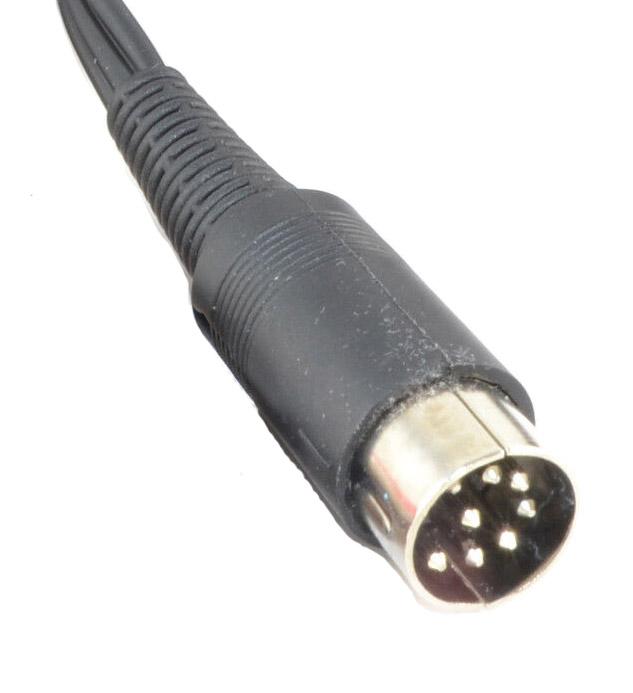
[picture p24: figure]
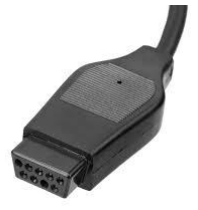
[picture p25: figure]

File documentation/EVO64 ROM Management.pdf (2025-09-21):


# “All your ROMs are Belong to us!”

EVO takes a unique approach towards allowing you to manage all of your system ROMS images and Character sets, by placing them into single-unified EEPROM. A variety of chip models in a variety of sizes are supported, from the W27C010 @ 128KB, up to the 27C801 @ 1MB. Your choice of chip depends on the number of ROM images you’d like to have onboard and available for handy access.

Inspiration for the switchable multi-ROM approach that EVO is using came from the
RePROM64, (http://henning-liebenau.de/reprom64/) which was originally designed by Henning Liebenau, however the implementation has been heavily modified for EVO, in that it’s fully integrated into the QAPLA (EVO’s Custom Developed PLA). (https://docs.google.com/document/d/1FS7WOKs4T5evn5urdY_PP3zLMoXYe2qxybZdXSJ7aDo/edit?usp=sharing)

The extra Kernal slots allow you to bring along your own custom ROMS (e.g., JiffyDOS, (https://www.go4retro.com/products/jiffydos/) JaffyDOS, (http://blog.worldofjani.com/?p=3544) SpeedDOS, (https://www.c64-wiki.com/wiki/SpeedDOS) etc.), so you can experiment with blazing-fast load times, predefined Function Keys and other extended features. You can also change your character sets to suit your mood or to match your system-specific build theme.

EVO has other tricks up its sleeve too. You can actually store your favorite Cartridge image files on the same EEPROM if you like. This gives you on-the-fly access to system diagnostics, utilities and even games, instantly, by simply moving a couple jumper caps*.

## Accessing different ROM images using jumpers

## Enabling access to Integrated Cartridge ROMs

*IMPORTANT NOTE: The system must be powered off before you attempt to move any of the jumper caps with your hand. However, you can completely automate the process of changing EVO configuration settings with the EVO’s Multi-Switch Module (MSM) (https://docs.google.com/document/u/0/d/1dWGB7BDyYcx3Wr9RBiRH9s14tvGeOEsOeAum02HLLDU/edit)


# Accessing your ROM images & Cart Files

The table below provides an outline of the different EEPROM types that are supported by EVO, along with the amount of ROM images and cartridge files that each can hold, as well as the memory addresses that each ROM type should occupy and the jumper settings that are required to access them.

Please note that the smallest EEPROM the EVO requires is the W27C010, which supports 128KB of ROM images. This provides access to 8x Kernal ROMs, 4x versions of Basic and 8x Character sets, but it will not have room left for any Cartridge files.

If you decide to GO BIG with the 27C801, with support for up to 1MB, you’ll have enough room for all the aforementioned ROM images, as well as 64x cartridge files, which can either by 8KB or 16KB each.

Use the link below to access and make a copy of the memory map sheet, so you can plan out your own EEPROM image layout:

EVO64 EPROM Memory Map (https://docs.google.com/spreadsheets/d/1CZf8Vy2QECNiIN6T1iT29r4AZUjwJyKktuMcQHm3Rco/edit?usp=sharing)

## Organizing your own EEPROMs

If you don’t mind rolling up your DIY sleeves, you can program your own EEPOMs for EVO, by using a TL866II or similar programmer. These are readily available on Amazon, Bay, AliEx and elsewhere, and they’re generally fairly inexpensive (all depends on current supply & demand).

The software interfaces for some programmers out there can be a little clumsy, but like everything else, they get much easier to use once you’ve felt your way through programming a couple ROMs.

As a frame of reference, you can use the steps on the following pages to complete the programming of your EEPROM(s), using a typical TL866II programmer (or clone).

# Programming with the TL866II / T48

Step 1: Download and install the latest version of the programming software from the XGecu website: http://xgecu.com/EN/Download.html

The site may initially load in Chinese, but don’t worry, a recent browser version should be able to perform a live translation. There should also be an option in the upper right hand corner of the loaded page to switch the language to English.

The programmer software is generally only available for Windows systems, although we’ve also had success using it from a Windows Virtual Machine running on our Mac systems, so this is an option as well.


Step 2: Connect your programmer to the USB port of the desktop system that you’ll be running doing the programming from. The system should auto-detect it as a USB device.


Step 3: Place your programmable ROM into the Programmer, using the correct chip orientation


Step 4: Launch the XGpro application and select the correct Programmer type


Step 5: Confirm the Initial Application Ready State
Step 6: Press the “Select IC” button to Change the EPROM Type


Step 7: Choose the correct programmable ROM chip type, using the “Search Device” field in the top right of the “Select Device” pop-up dialog box. If you bought the optional EVO Through-Hole parts BOM, it will have most likely come with an AMD29F040B
Step 8: Ensure that the correct ROM type now appears on the “Select IC” Button


Step 9: Refer to the EVO EEPROM memory map chart on the last page of this document to familiarize yourself with the memory locations for each of the system ROM types

Examples:

Step 10: Prepare to load the standard C64 Kernel ROM (901227) into the first available memory slot ($00000 - $01FFF), then press the “Load” button in the upper left corner of the main application to find the required ROM file.

NOTE: Commodore ROMs can typically be found on the internet and/or from the files that come with a copy of the VICE C64 emulator

Step 11: Take note of the default settings in the “File load Options” pop-up window.

File Format: Binary
To Region: Default
Load Mode: Normal
From File Start Addr(Hex): 00000
TO Buffer Start Addr(HEX): 00000
Clear Buffer when Loading the file: Clear buffer with default


Step 12: Look at the ASCII section of the main application window. You should now see evidence that the ROM file has been “pre-staged” to be loaded into the correct ROM file location on the ROM chip


Step 13: Using the scrollbar on the right-hand side of the ASCII section of the main application window, scroll down to memory location $01fff to confirm that the pre-staged ROM file image has been loaded completely.

Beginning at memory location $02000 you should still see empty memory space, which is indicated by the “dots” ……

Step 14: Reference the EVO EEPROM memory map again to take note of the memory location for the next ROM file image to be prestaged. In this case Kernal ROM #2 will be loaded into memory location $02000

Step 15: Now you will use the file load button in the main application window to add the next ROM file image. The process is a bit different from here, so please take note of the next details


Step 16: Configure the “File load Options” for the next ROM image, so it will be prestaged into into the next available memory location. Please note the important differences highlighted in the pop-up dialog box

File Format: Binary
To Region: Default
Load Mode: Normal
From File Start Addr(Hex): 00000
TO Buffer Start Addr(HEX): 02000
Clear Buffer when Loading the file: Disable


Step 17: Look at memory location $02000 in the ASCII section of the main application window. You should see evidence that the second ROM image has been loaded (e.g., the dots have been replaced by characters)


Step 18: You will effectively repeat steps 14-17 over-and-over-again, until you’ve fully pre-staged all of the ROM images that you’re interested in making available for your EVO system.

Please note that you do not need to have multiple Kernels, Basics and Character sets loaded, but you will need at least ONE of each, preferably loaded into the first memory slots for each ROM type

Kernal #1 - $00000-$01FFF
Basic #1 - $10000-$11FFF
Charset #1 - $18000-$18FFF


Step 19: Once all of your ROM images have been pre-staged, it’s time to write (burn) them to your programmable ROM by pressing the “PROG” button in the middle of the top toolbar in the main application window.
Step 20: Press the “Program”button on the “Chip Program” pop-up window.


Step 21: Monitor the programming progress
Step 22: Confirm that programming was successful

Step 23: Congratulations! Your ROM is now ready to be added into your EVO system!

Please note the orientation of the chip notch which is facing the rear of the EVO board (e.g., pointing towards the User, Dataset and cartridge ports, etc.)


# Tools & Processes for ROM Management


SX64Man’s Video on Multi-ROM Mgmt: https://www.youtube.com/watch?v=2JFnNYqYkGE Our friend and fellow EVO64 beta tester, Mario the SX64 man has made an excellent video that steps through the process that he’s using to combine multiple ROM & Cartridge images together, before writing them to the EEPROM.


The Igorware File Joiner Utility https://www.igorware.com/file-joiner/download In the SX64Man video above, there’s references to this Windows utility, which enables you to easily join files together, before attempting to write them to your EPROM (watch the video for details)

C64 Kernal Disassembly Info: https://www.pagetable.com/c64ref/c64disasm/ Info regarding ROM memory locations controlling boot-screen, side-borders and text colors, as well as the welcome message at the top of the screen


Breadbox64 C64 Kernel Modding: https://www.breadbox64.com/blog/c64-kernal-mods/ Useful blog post covering the ins and outs of editing Kernal ROMs to modify colors and boot screen text


C64 Kernal Mod v1.2 https://tools.anemo.se/c64/kernal-mod/?fbclid=IwAR3XjF_6u6Ar2ihbr977_nBuHplfdqcANs8DxmjN Gk5U-GLvEq0gQkK6-Ac (https://tools.anemo.se/c64/kernal-mod/) A useful online GUI tool that lets you load a Kernal image file, tweak the colors and boot text, then save the result to a file, which can be written to your EEPROM


EPROM Tool v1.1 https://drive.google.com/file/d/11YxtjMHBmiimIivL0H8MAqXKcpnHhDdX/view?usp=sharing (https://drive.google.com/file/d/11YxtjMHBmiimIivL0H8MAqXKcpnHhDdX/view?usp=sharing) This cool Windows-Only utility was developed by Six of DLOC and shared in the EVO64 Discord, in the #multi-rom-support channel (https://discord.com/channels/950181368711761931/1029893169371955220) by Dragos It’s an EVO specific ROM / CRT file joiner that lets you choose your EPROM, then load your image files into a binary blob for easier writing.

WinMerge File Compare https://winmerge.org/?lang=en Want to see what’s changed between two file versions? Then this handy Windows utility is your quick and handy go-to resource:

# EVO ROM Image Mapping Reference

Here’sDirect link to a Google Sheet with a detailed ROM Image map. You can download your own copy of this file to keep track of the ROM images that you’re using on your system.

EVO64 EPROM Memory Map (https://docs.google.com/spreadsheets/d/1CZf8Vy2QECNiIN6T1iT29r4AZUjwJyKktuMcQHm3Rco/edit)

Please note that the colored columns on the left hand side of the page identify the different EPROM types supported by EVO. The length of the column indicates how many ROM / Cart slots can be programmed and supported by each ROM type.

Please also take note of the “JTAG CRT EN” column, as this indicates whether EVO’s Cartridge Enable jumper needs to be in place for the specific ROM image to be enabled (located on the JTAG pin header bank)


# Changing your EPROM Type


EVO Rev1 boards ship with a 512K AM29F040B EPROM, which is capable of supporting up to:
- 8x Kernal ROM images @ 8KB each
- 4x Basics @ 8K each
- 8x Character sets @ 4K each
- 16x Cartridge ROM images @ 8K each
- 16x Cartridge ROM images @ 16K each

Other supported EPROM types include:
- 27C010 @ 128K
- 27C020 @ 256K
- 27C040 and 29F040B @ 512K
- 27C080 or 27C801 @ 1MB

The EPROM type selection is made on the underside of the EVO Rel 1 mainboard, by soldering (shorting) a set of jumper-pads that correspond to the EPROM type you intend to use, as outlined in this image:

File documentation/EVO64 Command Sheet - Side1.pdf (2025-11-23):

System Reset:; Firmware Reset:; Command Mode:; BASIC; CHAR SETS; KERNAL; d=Diag off D=Diag on; Diag; Mode; b=Beep off B=Beep on; Keyboard; Beep; SID Modes; Normal or; Reverse; SID #2; Addressing; Keyboard Beep:; beep; save1 - 8; load1 -

Mono or Stereo

Video Mode
PAL or NTSC

Saving a System State:
Loading a System State:

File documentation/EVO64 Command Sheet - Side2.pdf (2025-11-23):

SIE1-2; Disabling Cartridge / Diag Mode:; diag; video

Kernal Rom Selection:

Basic Rom Selection:

Character Set Selection:

Enabling Cartridge / Diag Mode:

SID Dual Mono Mode:

SID True Stereo Mode:

SID Normal / Reverse Modes:

SID Extended Address Modes:

VIC Video Mode:

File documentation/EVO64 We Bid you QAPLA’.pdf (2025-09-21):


## We Bid you QAPLA’ (That’s Klingon for “Success”)

For anyone that isn’t familiar with the Commodore 64’s Programmable Logic Array (PLA), it’s typically described as the “traffic cop” for the entire system. Its job is to tell chips when it’s their time to wake up, so they can listen and communicate on the system’s data and address buses. The PLA enables a bunch of cool tricks which have helped to make the C64 such a clever “success”. Examples include bank switching that allows the CPU and the VIC-II video chips to access the system’s memory independently, within a single, shared clock cycle.The PLA also enables the banking of the system’s ROM images with main memory, as well enabling various cartridge types to interface system resources.

More information on the C64 PLA Chip
https://www.c64-wiki.com/wiki/PLA_(C64_chip)

## Reworking the Classic

Over the years, there have been many attempts to replace the C64’s PLA. This is mostly due to the MOS 906411-01 PLA chip, which is found in most of the early “Breadbin” systems (e.g. assembly 250407, 250425 and 250466), being among the most common chips to fail. A faulty PLA will typically trigger the dreaded “black screen of death”, which has caused many users to throw their Breadbins into the proverbial dustbin.

The challenge with making a new PLA is to get all of the low level gate-logic to be 100% accurate, while ensuring that all of the output timings from the chip are perfect. There are some excellent resources and references available that can help with the core logic descriptions, but the timing tolerances can be pretty unforgiving, as just a few milliseconds too little or too much of a delay can cause a system to hang or freeze, or fail to boot entirely.

There have a number of great engineering efforts that have helped to demystify the inner workings of the PLA, from the early articles published in The Transactor magazine (March 1986, vol6, issue #5), to some great PLA white papers by Thomas ’skoe’ Giesel and Jens Shoenfled, through to the many efforts to produce highly effective PLA clones, such as Francois Leveille’s (aka Eslapion) PLAnktop and Passi Lassila’s (aka 1c3d1v3r) NeatPLA, among others.

We can thank folks like them for performing a ton of testing and stepping through the painstaking process of sampling and monitoring the C64’s PLA with their logic analyzers, under a litany of different conditions and system states, all while taking detailed notes of the precise timings, etc.

## Going “BIG” or Going Home!

When we were researching and testing various PLA alternatives for the EVO design, we ultimately chose to go with a CPLD-based approach. This decision was based on the flexible-programmability and configurable performance that can be achieved with CPLDs. It also makes it possible to seamlessly integrate all of the additional logic functions that are necessary to support flexible addressing for multi-SID support, and a highly configurable set of ROM images and cartridge bank selections, without having to add a ton of extra discrete logic chips onto the mainboard itself.

It’s important to acknowledge the great work done by Henning Liebenau, on his MixSID and RePROM64 designs, (https://github.com/hbekel) which provided some early insights and inspiration for both of these solutions. However, the actual technical implementations that ultimately made their way into EVO’s QAPLA’ design are fundamentally unique and distinct, which have helped to make the QAPLA’ a one-stop-shop for all of EVO’s chip and system control logic.

The EVO team have rigorously tested QAPLA’ for performance, compatibility and stability, across a wide range of timing-sensitive games and demoscene productions. So, at this stage we’re quite confident that it’s on par with the best PLA solutions available for the C64. When you combine this robustness with the added multi-SID and multi-ROM capabilities, we’re happy to call QAPLA’ a success!


Using a set of dip-switch arrays with the QAPLA will make it easy to set logic positions using only your fingers

You can also choose to use standard 2.54mm pitch header pins, which will allow you to use jumper caps to set logic positions. This approach makes it possible to retrofit an automated ROM switching tool, such as the EVO Multi-Switch-Module (MSM). (https://retrospective.shop/evo-multi-switch-module-msm/) Needless to say, building and configuring a KeyMan64 for use with EVO is beyond the scope of this document.

Naturally, we think the best option for managing all of your system settings is with an EVO Multi-Switch Module (MSM). The MSM comes with a ROM-SID module that you place on top of your configuration header pins. The ROM-SID module is connected to the primary MSM module, which intercepts the keystrokes from your keyboard. When you press the command-sequence hotkey and enter a command, your settings will change dynamically, without having to touch your jumpers.


### Informative Links

EVO’s optional Multi-Switch-Module (https://docs.google.com/document/u/0/d/1dWGB7BDyYcx3Wr9RBiRH9s14tvGeOEsOeAum02HLLDU/edit) for config state mgmt.

EVO’s integrated Multi-SID (https://docs.google.com/document/d/1XS_R7kihAPjszfNpAIuLDzaF_hOIagSV1rWBT-0Q7ag) implementation.

EVO’s integrated Multi-ROM (https://docs.google.com/document/d/1fZz-1mBjhx3ufDgjr7Vkx1MRPd-1uP_nOwPE4PMlqfg) implementation.

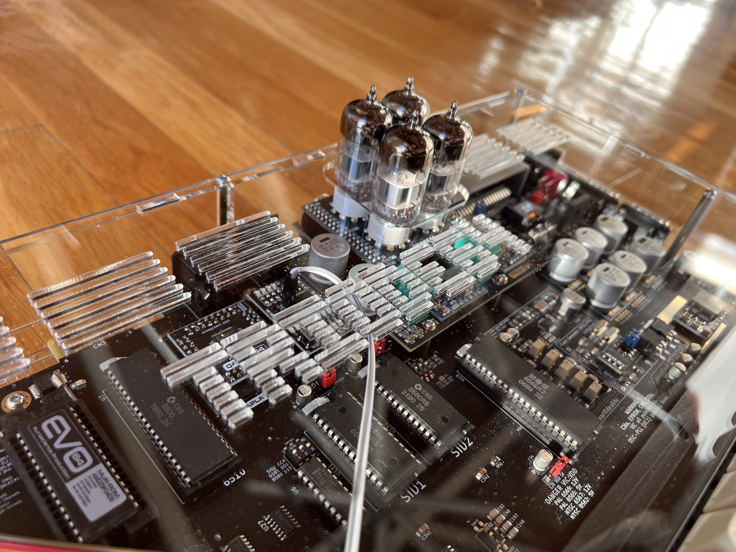
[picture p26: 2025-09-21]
image-gallery/EVO64 with Triode64 in Plexilaser - Left angle top.jpeg

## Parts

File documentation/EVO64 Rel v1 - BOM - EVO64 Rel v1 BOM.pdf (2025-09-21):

# EVO64 BOM - Production Release v1

Updated: Aug 12th 2023

BOARD REFERENCE | QTY | VALUE | DESCRIPTION | MANUFACTURER PART # | MOUSER PART # | COMMENT
POWER Pack SW1 | 1 | DPDT Power Switch | Recover from original system or NEW | SKY KS-SP-222A or SALECOM R8017L-R21 | Not available | Try eBay CN7 | 1 | DIN7 Power connector | 7 pin round DIN 45329 | Original computer / NEW | Not available | Try Ali Express VR2 | 1 | 7805 @ 1A | 5v regulator 1A TO-220 | L4941BV | 511-L4941BV CR4 | 1 | Bridge Rectifier @ 4A | Flat, inline package | GBU4G | 512-GBU4G | No Longer Required for Boards dated 20230730 or newer
JP30 | 1 | Header - Male 2x5 | Crowbar protection. Close both +5v | 10129381-910001BLF | 649-1012938191001BLF
Jumper caps | 2 | Jumper Cap - Female 1x2 | Various jumper caps to short required header connections | M7582-46 | 855-M7582-46
L4 | 1 2 | 250V,3.8mH,2.1A,150mOhms Fuse Clip | AC Line Filter / Choke Original computer / NEW Eaton Fuse Clip 5mm | SSR10V-21038 AP/HTC-200M | 80-SSR10V-21038 F1 504-AP/HTC-200M
FUSE | 1 | 1A | Glass Fuse, Small Form Factor 5x20mm 1A @ 250VAC fast blow | BK/S500-1-R | 504-BK/S500-1-R
HEATSINK | 1 | Heatsink for 7805 | TO220 package @ 30mm | 240-118ABEH-22 | 567-240-118ABH-22
SOCKET Set U1,U2 | 2 | 40 PIN DIP Wide | Socket for 6526 CIA | 1-2199299-5 | 571-1-2199299-5 U7 | 1 | 40 PIN DIP Wide | Socket for 6510 or 8500 CPU | 1-2199299-5 | 571-1-2199299-5 U19 | 1 | 40 PIN DIP Wide | Socket for 6569/8569 (PAL) or 6567/8562 (NTSC) VICII | 1-2199299-5 | 571-1-2199299-5 U3 | 1 | 32 PIN DIP Wide | Socket for 27C010 / 20 / 40 / 80 Series EEPROM | 1-2199300-2 | 571-1-2199300-2 U181,U182 | 2 | 28 PIN DIP Wide | Socket for 6581/8580 SID or Various Clones | 1-2199299-2 | 571-1-2199299-2 U6 | 1 | 18 PIN DIP Narrow | Socket for 2114 SRAM for Video | 1-2199298-5 | 571-1-2199298-5
PIN Pack CN1 | 1 | Header - Male 1x20 | Keyboard (remove pin 2 from connector) | 10129378-920001BLF | 649-1012937892001BLF SID1, SID2 | 2 | Header - Male 1x3 | Selects SID voltage (12v for 6581, 9v for 8580, open for most clones) | 77311-818-03LF | 649-77311-818-03LF VIC-II | 1 | Header - Male 1x3 | Selects VIC-II voltage level (12v for 6567/6569, 5v for 8569/8562) | 77311-818-03LF | 649-77311-818-03LF CN10 | 1 | Header - Male 1x3 | Standard power LED for case enclosure | 77311-818-03LF | 649-77311-818-03LF
JP12 | 1 | Header - Male 1x3 (optional) | Test points for NE556 Timer & Reset Signal only (optional - never close!) | 77311-818-03LF | 649-77311-818-03LF
JP11, JP25 | 2 | Header - Male 1x2 | Reset (optional) | 10129378-902001BLF | 649-1012937890201BLF QAPLA' | 4 | Header - Female 2x8 | QAPLA | 68683-308 | 649-68683-308 RePROM | 1 | Header - Male 2x8 | Selects ROM and Cartridge Images | 10129381-916001BLF | 649-1012938191601BLF NuTube64 / Triode64 | 1 | Header - Male 2x8 | Power and audio signal routing for Triode64 and NuTube64 (optional) | 10129381-916001BLF | 649-1012938191601BLF QAPLA' JTAG | 1 | Header - Male 2x5 (optional) | JTAG Programmer for QAPLA CPLD (optional - not reqquired) | 10129381-910001BLF | 649-1012938191001BLF MixSID | 1 | Header - Male 2x4 | Selects configuration and address selection for SIDs | 10129381-908001BLF | 649-1012938190801BLF
IN/OUT Connector | 1 | Header - Male 2x4 | Test points for VIC-II Chroma & Luma signals, as well as SID audio in & out | 10129381-908001BLF | 649-1012938190801BLF
Jumper caps | 18 | Jumper Cap - Female 1x2 | Various jumper caps to short required header connections | M7582-46 | 855-M7582-46
PORT Pack CN6 | 1 | Cartridge port connector | Edge connector, dual row, female, 22x2 (44 pos) 0.100” | 395-044-559-212 | 587-395-044-559-212 CN8,CN9 | 2 | DE-9 Joystick port connector | DE-9, multiple options | 621-009-260-043 | 587-621-009-260-043 CN4 | 1 | DIN6 IEC port | 6 pin round DIN 45322 | Original computer / NEW | Not available | Try Ali Express CN5 | 1 | DIN8 Video port connector | 8 pin round DIN 45326 | Original computer / NEW | Not available | Try Ali Express
PREMIUM Pack | OPTIONAL upgrades - THESE PARTS ARE NOT REQUIRED for a base EVO64 Build
U1,U2,U7,U19 | 4 1 2 | 40 PIN Aries LP ZIF Sockets 32 PIN Aries Full Height ZIF Socket 28 PIN Aries LP ZIF Sockets | Low profile zif sockets for CIA, CPU & VICII Full height zif socket for ROM EPROM, as low profileis not available Low profile zif sockets for SID chips | 40-526-10 32-6553-10 28-526-10 | 535-40-526-10 U4 535-32-6553-10 U181,U182 535-28-526-10
L4 | 1 | Coilcraft AC Filter Choke | Low Noise AC Filter Choke (SMD Part, please review BOM notes) | CG3528-ALD | 994-CG3528-ALD
VR2 | 1 | EVO PWR 5v Switching vReg | Ultralow noise 5v switching regulator, designed by EVO team | https://retrospective.shop/evo64-rev-1-premium-ultra-low-noise-components/ Not available | EVO64 Exclusive REPROM | 1 | DIP Array Dongle 8 positions | Convenient dip switch array that sits on top of 2x8 male headers for ROM config | https://retrospective.shop/evo64-rev-1-premium-ultra-low-noise-components/ Not available | EVO64 Exclusive MIXSID | 1 | DIP Array Dongle 4 positions | Convenient dip switch array that sits on top of 2x4 male headers for SID config | https://retrospective.shop/evo64-rev-1-premium-ultra-low-noise-components/ Not available | EVO64 Exclusive CROWBAR, SID1, SID2, VICII | 5 | Jumper Caps - RED | RED caps indicate configurable POWER settings | M7581-46 | 855-M7581-46 VICII PAL/NTSC, JTAG CRT EN | 3 | Jumper Caps - BLUE | BLUE caps indicate configurable CONTROL settings | M7583-46 | 855-M7583-46

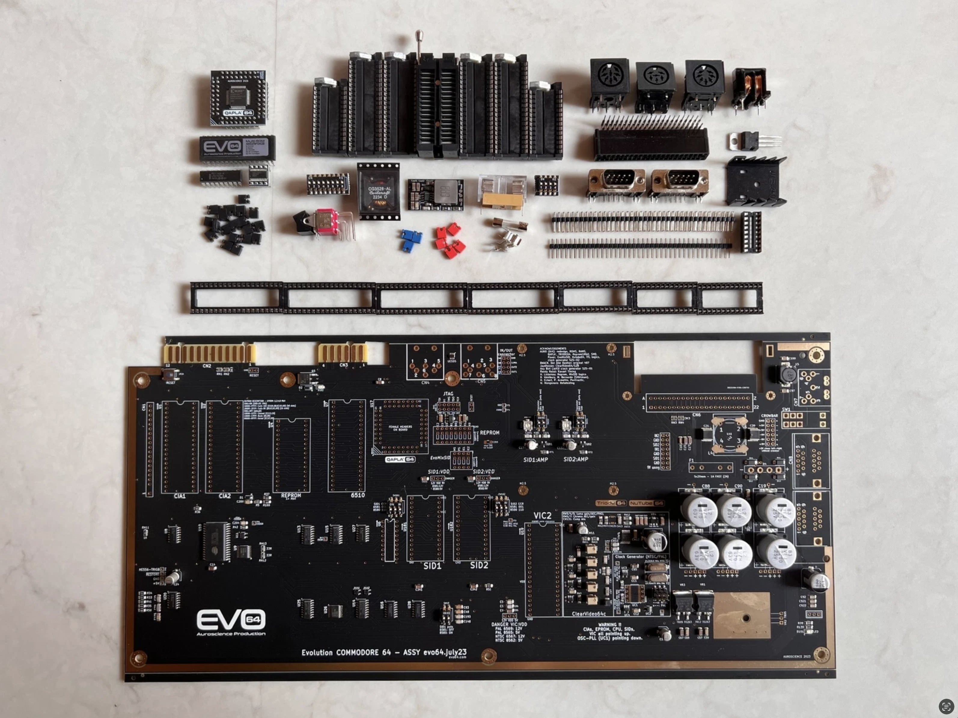
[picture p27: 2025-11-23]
image-gallery/EVO64_Rel1 - Complete Parts BOM.png

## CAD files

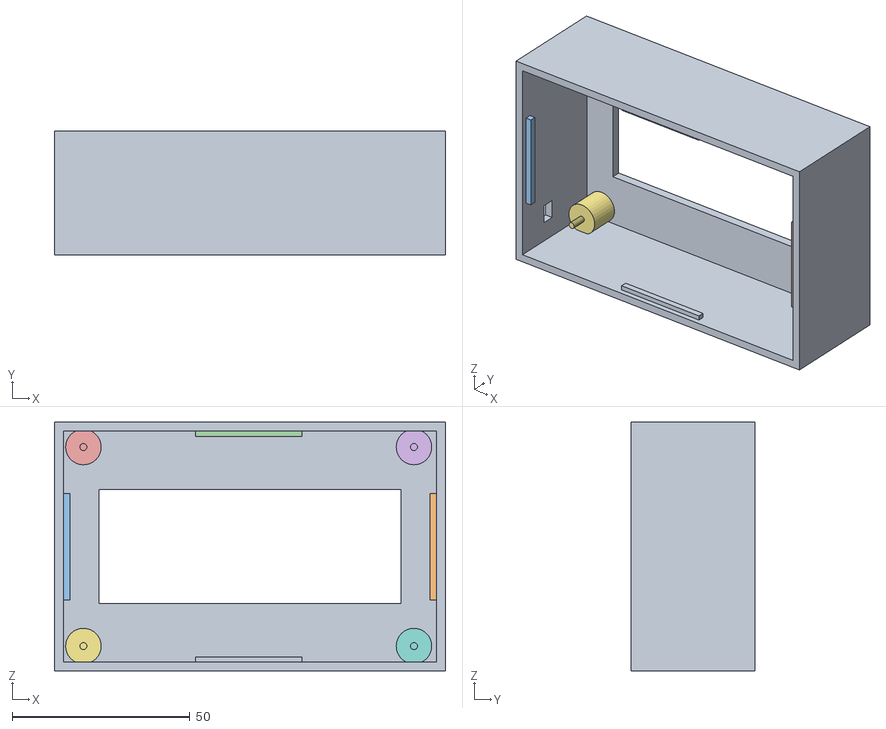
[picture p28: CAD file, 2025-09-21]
3D-printables/LCD 20x4 Mount - Rounded/4x20 LCD Box/lcdbox_back.obj
110.0 x 35.0 x 70.0
Pin_4
Pin_3
Pin_2
Pin_1

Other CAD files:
3D-printables/Cart Shield Cover by Sedor/CartridgePortCover_V2.2.stl
3D-printables/Keyboard Mounts for C64c case by Jaystonian/tastaturhalter_EVO64_JRW.stl
3D-printables/Keyboard Mounts for C64c case by Perifractic/LSC20_tasthalt_r_Edited.stl
3D-printables/Keyboard Mounts for Plexilaser case by Sedor/Plexilaser_Frontkeil_V1.0.stl
3D-printables/LCD 16x2 Mount/lcd_housing.STL
3D-printables/LCD 20x4 Mount - Flat/LCD_Box.stl
3D-printables/LCD 20x4 Mount - Rounded/4x20 Bezel only/CCR10SPRO_msm64c.stl
3D-printables/LCD 20x4 Mount - Rounded/4x20 LCD Case - 6032325/LCD_back_case.stl
3D-printables/MODULR Case, Keyboard Mount/KBFixBack#Dprint.stl
3D-printables/MSM Display Mount for Plexi-case by Sedor/MSM_Display_Lid_V1.1.stl
3D-printables/MSM Mount - RF Fuzion Breadbin - 40x2/2x40 LCD-Mount 4 MSM.stl
3D-printables/MSM Mount Hex Standoffs (BattleQuest)/hex-standoff-10mm.stl
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

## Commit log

2025-09-21 Initial commit - documents, ibom.html, images and 3D printables
    [2x16 with cutout.stl, 2x40 LCD-Mount 4 MSM.3mf, 2x40 LCD-Mount 4 MSM.stl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]
2025-09-21 Configure Git LFS for large files
    - Add .gitattributes to track *.pdf, *.png, *.jpg, *.jpeg, *.stl, *.3mf, *.xlsx
    - Migrate all existing large files to Git LFS
    - This resolves GitHub file size limits, including the 123MB DIY Build Guide PDF
    [2x16 with cutout.stl, 2x40 LCD-Mount 4 MSM.3mf, 2x40 LCD-Mount 4 MSM.stl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]
2025-09-21 BOM Images and Key Feature updates
2025-09-21 File cleanup
    [2x40 LCD-Mount 4 MSM.3mf, C64c_Key_Mnts_RR.3mf, Display_4x20LCD_casing_v5.step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]
2025-11-23 Added printable MSM Command Sheets by Retrosarge
